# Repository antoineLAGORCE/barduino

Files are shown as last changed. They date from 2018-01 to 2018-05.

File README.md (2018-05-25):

# BARDUINO ARNOUX LAGORCE GUADALIX
CE PROJET EST REALISE DANS LE CADRE DE:
ALLER POLYTECH NICE-SOPHIA

## DESCRIPTION DU PROJET
  Nous allons sortir du traditionnel. Notre projet se base sur le même principe qu'un barduino comme on les a déja vu auparavant
sauf que nous allons le faire avec une esthétique circulaire en plus d'une reconnaissance vocale transmise par technologie
bluetooth.
  En effet nous allons faire bouger les bouteilles, plaçant le verre fixe sur la base. Un moteur pas à pas fera bouger le support plaçant la bouteille désirée sur le verre. Une fois sa tâche accomplie, la tige rentre en jeu pour pousser le doseur à l'aide d'un servo moteur.
  Tout cela est possible gràce aux pièces modélisées à notre choix sur l'ordinateur qui nous permettent de tout relier.
  Nous avons choisi 7 cocktails de base et l'Aléatoire.

## LISTE DU MATRIEL NECESSAIRE
  - [x] Servo moteur;
  - [x] Moteur pas à pas;
  - [x] Puce bluetooth;
  - [x] Tige imprimée en 3D avec son support vertical;
  - [x] Support de fixation du moteur pas à pas modélisé;
  - [x] Helice entrainant le support des bouteilles;
  ### Dont le matériel à commander est
  - [x] Support pour les bouteilles
  Support pour les bouteilles Support por les bouteilles

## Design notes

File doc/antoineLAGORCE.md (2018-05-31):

Séance du 21/12/2017:
Nous allons faire un barduino a reconnaisance vocale.
Nous hesitons a faire un bar circulaire ou murale
cela conciste a demander un cocktail a haute voie et notre barduino réalise notre demande. 
nous avons vu sur https://www.youtube.com/watch?v=K0hTqzQLlWo un exemple de barduino avec des distributeaurs 

Séance de 10/01/2018:
nous sommes donc partie sur un barduino circulaire. 
nous alons faire tourner un verre comme un "petit train" qui va se positionner en dessous des bouteilles avec une petite tige qui va monter et descendre pour appuyer sur les doseurs et verser une dose de liquide.
nous avons commencé a lister le matériels et les techniques que nous allons utiliser pour concevoir notre barduino. 
nous avons encore quelque hesitations sur la technique pour faire tourner le verre sur des rails (comme un petit train)
nous avons réalisé un planning peu détailler de ce que nous allons faire. 

séance du 19/01/2018:
nous avons finalisaé la conception de notre projet. en effet, nous avons décidé de faire tourner les bouteilles et non le verre. 
puis, nous avons commandé le materiel principale dont noud avons besion. 

séance du 19/02/2018:
nous avons fini le programme bluetooth.
on a fait une liste des objets a découpés:
- 6 cercles (diametre de 8cm) qui vont etre fixés sous les dosseurs pour répartir et augmenter la force de la tige qui va ouvrir les valves
- une tige de longueur 13 cm et de diamtre 1 cm
- un demi-cercle de diametre 8cm qui va etre fixé sur la tigue pour répartir la force de la tige 
- des plaques en bois que nous allons découpé pour fixer le cervo moteur, la tige et pour faire un socle pour le verre afin de cacher le systeme pour faire monter la tige

séance du 12/03/2018:
nous avons assambler les programmes des deux moteurs avec celui du bluetooth. c'est a dire que : on envoyer une commande avec l'application sur le téléphone, en fonction de la commande, le moteur à courant continue tourne dans différents sens (dans le but de faire tourner l'axe avec les bouteilles et de s'arreter à l'endroit où l'on veut) puis le servo moteur se met en marche afin de monter
une tige qui verse la bouteille dans le verre, puis à nouveau le moteur à courant continue, le servo moteur ... 

séance 5/04/2018:
nous avons trouvé une application sur le téléphone qui comprend la reconnaissance vocale. nous avons rencontré quelques problème pour pouvoir mettre ce que nous disions sur le telephone dans une variable afin de pouvoir faire les différents coktails.

seance 2/05/2018 :
nous avons réglé les problèmes liés à la reconnaissance vocale. 
j'ai réflechis à l'assemblage des pieces (par exemple viser un support en bois sur la tige qui permet d'actionner les doseurs). j'ai finis de limer les pièces imprimer à l'imprimante 3D pour qu'elles puissents s'assembler. 

seance du 7/05/2018:
j'ai recuperé les rislans pour pouvoir attacher les cercles en bois aux doseurs afin de répartir la force qui va être appliquée. j'ai découpé les orreils du moteur car elles empechées les bouteilles de tourner.

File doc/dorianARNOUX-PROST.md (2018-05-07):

Séance du 21/12/2017 :
On a assemblé le trinome composé de Antoine Lagorce, César Guadalix et moi-meme. On a choisi de faire un barduino avec une spécialité : la reconnaissance vocale. On pense faire un barduino avec verre fixe, et c'est les bouteilles qui tournent au dessus sur un axe circulaire.

Séance du 10/01/2018 :
Après de nombreux schémas, on a trouvé le "design" de notre projet, nous allons utiliser un cylindre en PVC de 140mm de diamètre et faire tourner autour un petit train sur des rails qui va contenir l'arduino + moteur et soutenir la plateforme du verre. Nous voulions commander le matériel cette semaine mais on ne trouvait pas quel système utiliser pour faire tourner la plateforme autour de l'axe central (qui est fixe). On a partagé les taches pour la semaine prochaine de manière a etre plus efficaces.

Séance du 19/01/18 :
Liens pour petits trains :
https://www.ebay.com/itm/LIONEL-FASTRACK-LOT-TRACK-INNER-SIDING-PACK-switch-train-fast-loop-6-12044-NB-/310541188464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
http://www.newhallstation.com/store/product_info.php/products_id/1041
http://www.rueducommerce.fr/produit/touslescadeaux-train-electrique-de-noel-24-pieces-30177768/offre-73395642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

Liens pour doseurs :
https://www.cdiscount.com/vin-champagne/accessoires-vin/distributeur-de-boisson-design-distributeur-alcoo/f-1290911-tec4260435991311.html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|mp

Seance du 19/02/2018 :
J'ai travaillé sur le servo-moteur, trouvé un moteur assez puissant pour lever les valves et regardé quelques codes pour me souvenir de comment ils fonctionnent. J'ai fait fonctionné la puce HC-06 qui ne fonctionnait pas la semaine dernière. 

Séance du 12/03/2018:
J'ai réalisé les différentes fonctions pour chaque cokctail, j'ai du donc assembler les codes pour bluetooth, le servo moteur et le moteur pas a pas  dans un seul programme regroupant tous ces programmes. Pour chaque fonction, il a fallu utiliser des différentes combinaisons entre l'ordre des fonctions prédéfinies pour le servo moteur et le moteur pas à pas.

Séance du 05/04/2018:
J'ai modifié les fonctions des cocktails de maniere a ce que les cables ne s'emmelent pas quand la machine tourne. J'ai aussi testé l'assistant de commande vocale google, pour que le programme réagisse au noms des cockatils.

Seance du 02/05/2018:
J'ai dessiné les parties rondes que l'on va fixer sur les doseurs du bar, nous allons finalement partir sur du bois au lieu du plastique (fragile) de l'imprimante 3D.

Séance du 07/05/2018:
Dans la semaine on est allé récupérer les nouvelles pièces à l'imprimante 3D et découpé les rondins de bois que nous allons fixer sur les doseurs. Je me suis renseigné sur les tiges en pvc qui existent afin d'en avoir sous la main si la tige en plastique de l'imprimante 3D n'est pas assez solide.

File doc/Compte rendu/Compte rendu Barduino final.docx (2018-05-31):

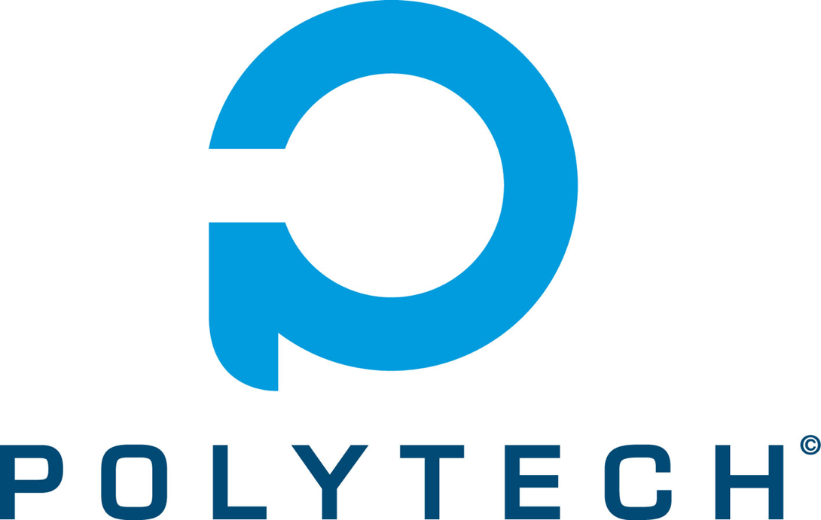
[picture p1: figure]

Compte Rendu Projet Arduino

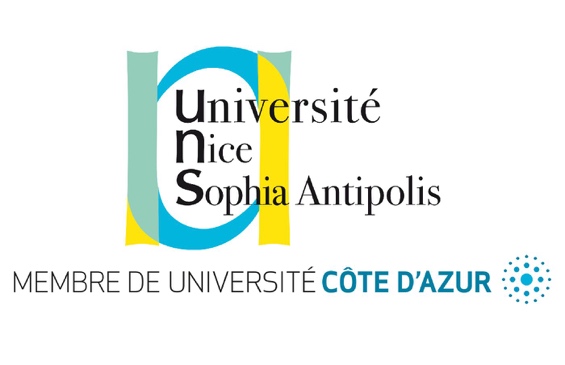
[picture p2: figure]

BARDUINO

Sommaire

I. Introduction
II. De la théorie à la pratique
III. Matériel
IV. Planning
V. Code
VI. Montage
VII. Tests
VIII. Conclusion
I. Introduction

Au cours de cette deuxième année de classe préparatoire nous avons eu l’occasion de pouvoir réaliser notre premier projet officiel en électronique grâce à la technologie Arduino. Dans ce cadre nous avons décidé de mettre en œuvre un bar connecté par technologie Bluetooth à un smartphone courant.

Nos motivations commencent là. De nos jours, 73% des français possèdent un smartphone, ce qui veut dire que ces mêmes 73% ont la possibilité de se faire servir un verre automatiquement commandé avec un téléphone sans avoir besoin de bouger du canapé. Nous sommes partis sur l’originalité d’un Barduino circulaire avec une commande vocale adaptée aux boissons préférées de l’utilisateur. Nous avons pu donc au cours de la réalisation combiner trois domaines qui nous ont permis de tout mettre en relation comme le sont l’informatique, l’électronique et la mécanique.

Nos objectifs principaux ont été de faire un bar qui fonctionne correctement avec une originalité ajoutée : faire le premier Barduino circulaire afin d’ajouter un côté innovatif et design à celui-ci. Nous avons aussi voulu innover du côté pratique en intégrant au Barduino un principe de commande vocale simulant un vrai bar. En effet, le côté « user-friendly » était important pour nous ; nous ne voulions pas que l’utilisateur ait des difficultés à manipuler ce Barduino.

II. De la théorie à la pratique

Avant de commencer à réaliser notre Barduino, il était évident de définir précisément les spécificités de celui-ci. Plusieurs options se sont rapidement mises en place pour réaliser les différentes caractéristiques techniques de notre Barduino.

Notre objectif était de réaliser un Barduino qui fonctionne parfaitement. Pour cela, deux options s’offraient à nous : faire tourner un verre sous les bouteilles ou bien faire tourner les bouteilles avec un verre fixé.

Nous voulions dans un premier temps faire tourner le verre à l’image d’un petit train électrique. Mais, un problème est vite apparu, nous n’avons pas trouvé de rails avec un diamètre suffisamment petit pour faire coïncider le verre avec les bouteilles.

Nous avons donc pris la décision de faire tourner les bouteilles au-dessus d’un verre fixe.

Puis, nous devions trouver un moyen de verser les bouteilles dans le verre. De nouveau, plusieurs options s’offraient à nous. Tout d’abord un système de pompe ou bien un système de doseurs avec un mécanisme qui l’actionnerait. Par souci d’esthétique nous avons décidé d’utiliser les doseurs.

III. Matériels

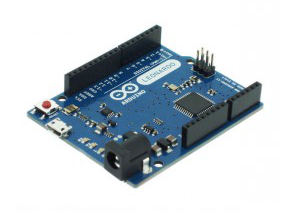
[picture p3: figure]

Tout d’abord nous disposons de notre carte Arduino.

Nous avons commandé la base de notre projet qui comporte déjà 6 doseurs :

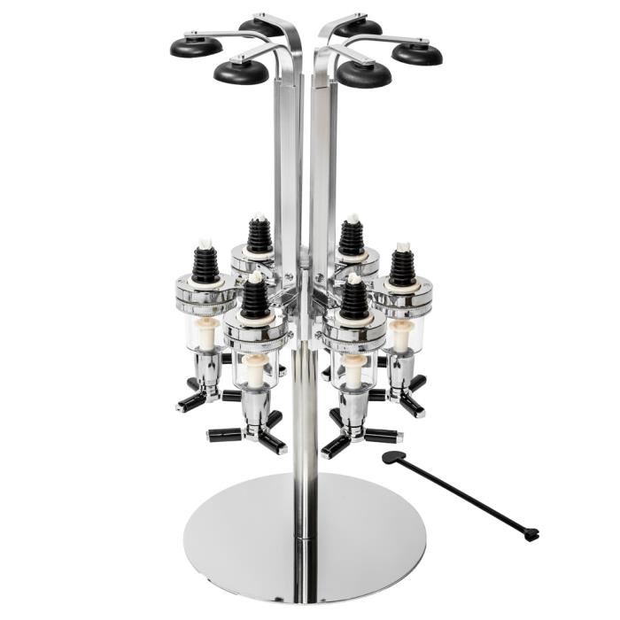
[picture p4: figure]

Les doseurs étant déjà positionnés sur un roulement à billes, il nous fallait un moteur pour pouvoir les faire tourner sur commande.

Nous avons donc décidé d’utiliser un moteur pas à pas car celui-ci est très précis et cela nous permettait de faire tourner les bouteilles et de les arrêter précisément à l’endroit où le verre est positionné. De plus, nous avons imprimé en 3D une pièce qui s’emboite avec le moteur pour que celui-ci puisse avoir de l’incidence sur les bouteilles.

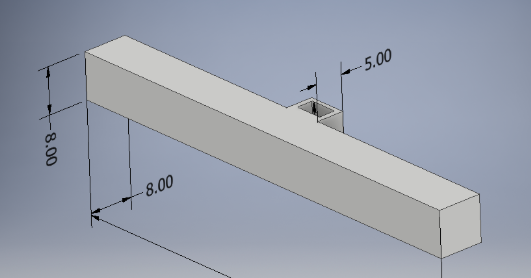
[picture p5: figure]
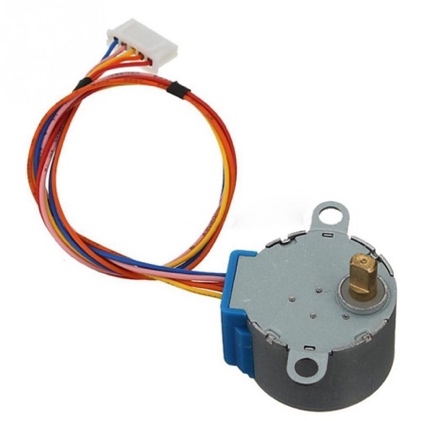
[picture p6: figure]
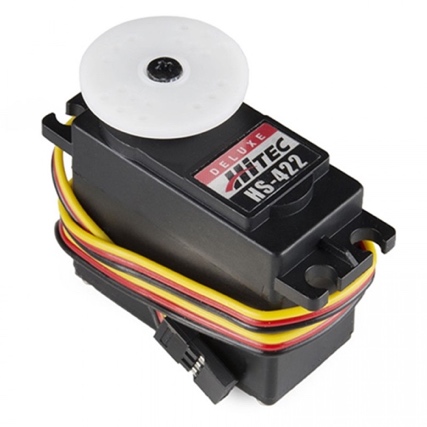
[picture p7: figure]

De plus, le système permettant d’actionner les doseurs comporte deux servo-moteurs avec une tige et une pièce servant à la maintenir pour chaque servo-moteur.

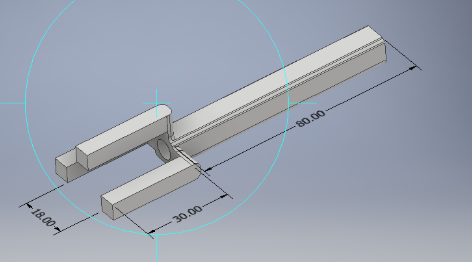
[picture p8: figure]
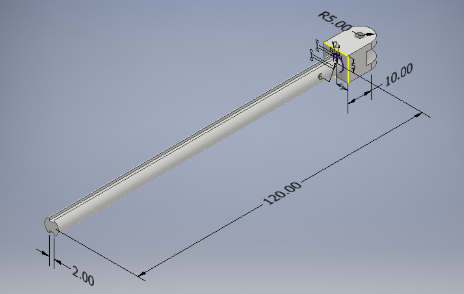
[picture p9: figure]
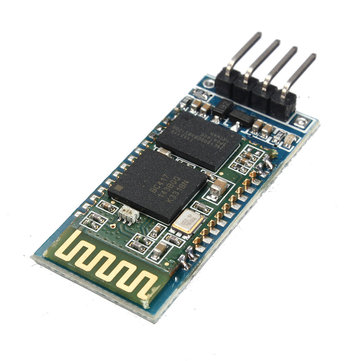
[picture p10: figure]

Enfin, nous disposons d’une puce Bluetooth HC-06 pour effectuer la connexion entre le téléphone et notre projet.

IV. Planning
- Fin Décembre – Fin Janvier :

Réflexion sur le choix du projet et son fonctionnement.

- Début Février:

Choix de faire tourner le support au lieu de faire tourner le verre autour.

- Février :

Codage des fonctions permettant d’activer les moteurs et de créer les différents cocktails.

- Mars :

Conception des pièces à l’imprimante 3D.

- Avril :

Assemblage des moteurs avec la base.

- Fin Avril début Mai :

Tests et faibles modifications de la structure.

V. Code
1. Bluetooth

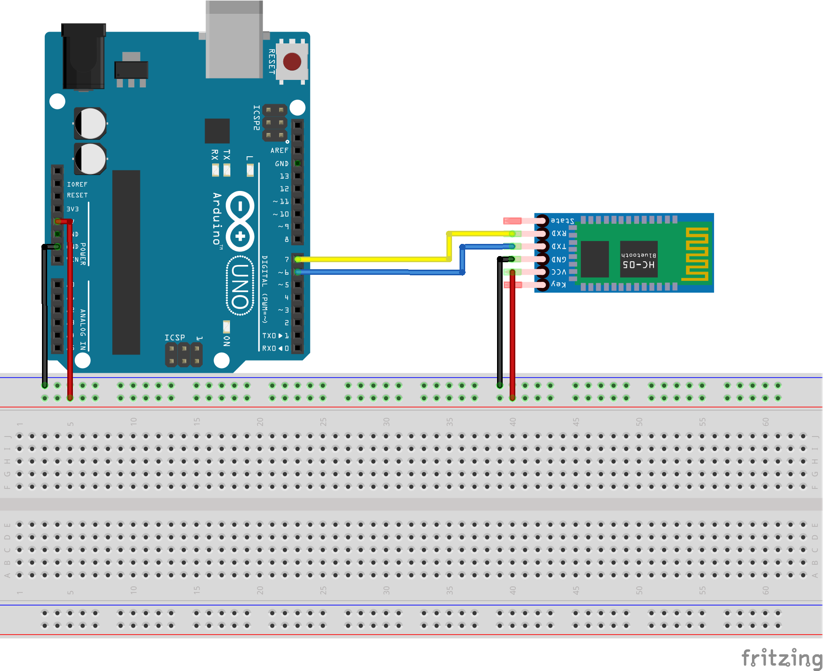
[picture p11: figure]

Nous avons commencé par reprendre ce que nous avions vu en cours afin d’effectuer la connexion Bluetooth entre la puce HC-06 et le téléphone. Nous avons donc effectué les branchements suivants :

Le but de notre projet étant de commander par la voie un cocktail, nous devions trouver un système de reconnaissance vocale. Nous avons donc utilisé une application (Arduino Voice Control) comprenant déjà la reconnaissance vocale et qui renvoie en chaine de caractère ce qui a été dit par l’utilisateur. Ensuite, nous avons codé notre programme afin que chaque cocktail que nous avons défini réalise l’action qu’il doit réaliser. Pour cela, nous avons utilisé une variable pour chaque cocktail avec des instructions différentes pour chacun. Donc si la commande effectuée par l’utilisateur correspond bien à un cocktail, alors les actions à effectuer sont exécutées. Voici un exemple de cocktail :

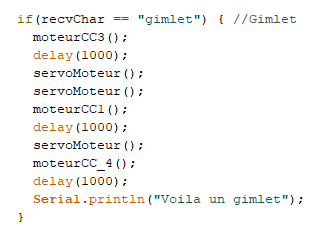
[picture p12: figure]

2. Moteur pas à pas

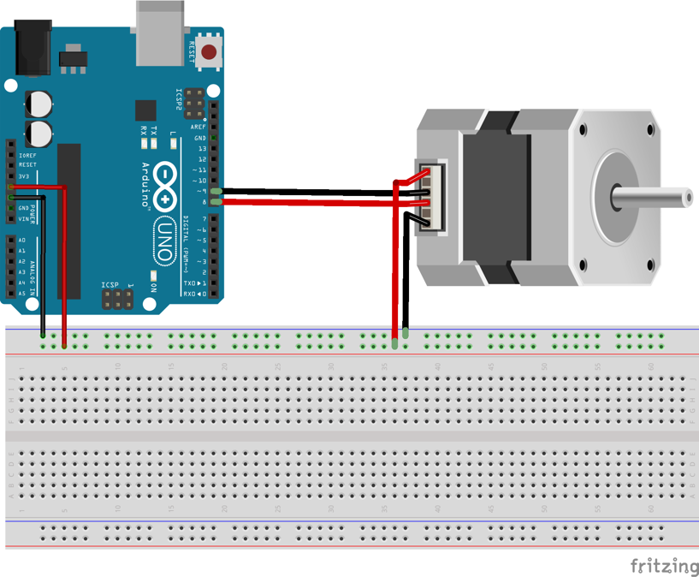
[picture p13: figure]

Nous avons effectué les branchements suivants :

Le but du moteur pas à pas est de faire tourner les bouteilles. Comme nous disposons de 6 bouteilles, ce moteur devait être capable de faire précisément un-sixième de tour. Ici, on définit dans Paso un tableau de séquences de bits qui vont permettre de faire bouger le moteur. La fonction moteurCC1() correspond à un sixième de tour, elle doit donc permettre de déplacer le bar jusqu'à la bouteille de gauche.

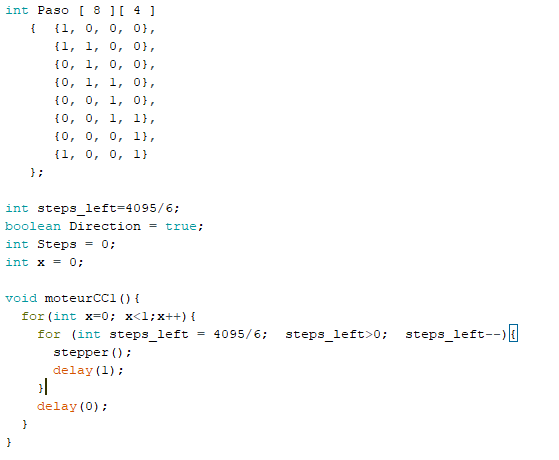
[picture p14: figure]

3. Servo moteur

Nous avons effectué les branchements suivants :

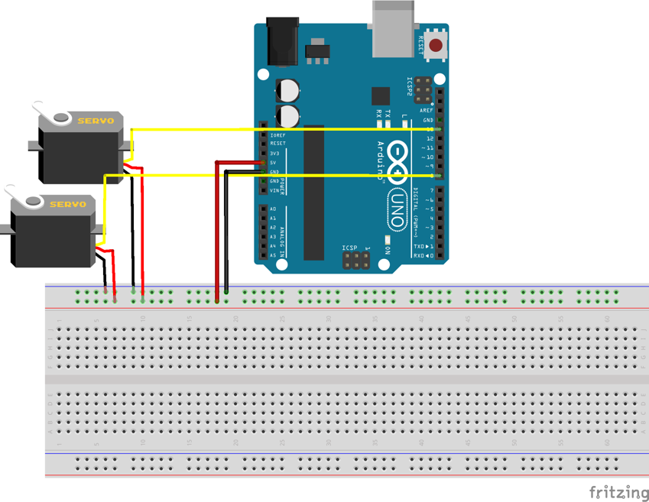
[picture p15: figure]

Le but du servo-moteur est de faire monter une tige, la faire tenir pendant quelques secondes et la redescendre. Nous avons donc réalisé deux boucles : dans la première boucle le servo-moteur se positionne à la position initiale, il effectue une rotation de 55 degrés puis il revient à sa position initiale dans la deuxième boucle. Mais, nous avions besoin qu’il reste à sa position intermédiaire pendant quelques secondes. Pour cela, nous avons ajouté une condition avec un temps d’attente lorsque le servo moteur se trouve à cette position. Voici notre fonction qui actionne le servo moteur :

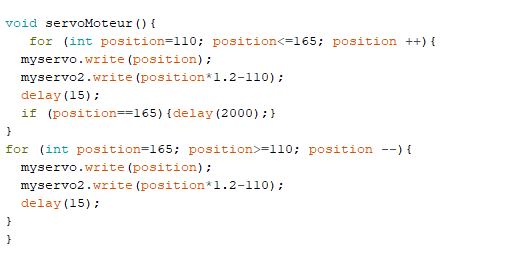
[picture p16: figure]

VI. Montage

Après avoir récupéré les pièces imprimées en 3D, nous avons dus assembler celles-ci. En effet, toutes les pièces que nous avons imprimées sont nécessaires pour que nos moteurs puissent agir sur la base de notre projet.

Tout d’abord nous avons fixé des cercles en bois sur chaque doseur et également vissé un cercle en bois à la tige d’un servo-moteur afin de répartir et donc d’augmenter la force de la tige qui provient du servo moteur dans le but d’actionner les doseurs.

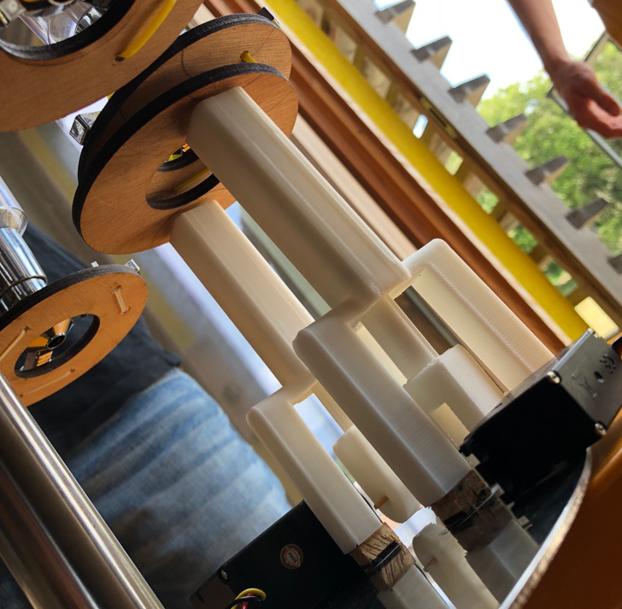
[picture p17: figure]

Ensuite, nous avons assemblé la pièce que nous avons conçu pour qu’elle puisse s’emboiter avec le moteur pas à pas. Le but étant de pouvoir faire tourner les bouteilles.

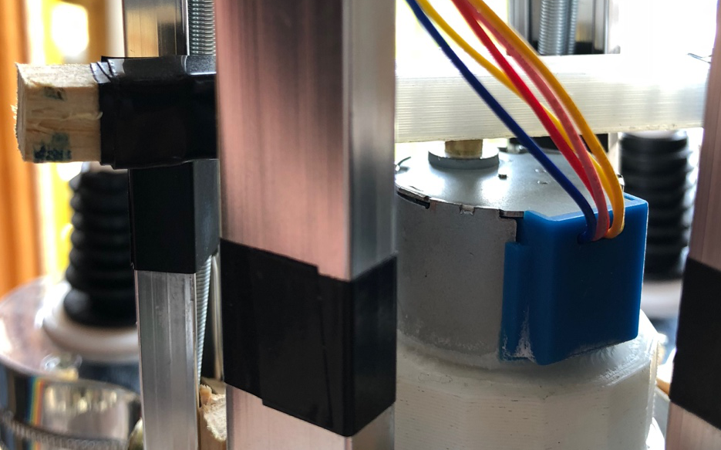
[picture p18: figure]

Enfin, nous avons assemblé les différentes parties de code que nous avions effectuées pour faire fonctionner les moteurs à tour de rôle en fonction du cocktail demandé.

Pour finir, nous avons effectués le branchement de tout le matériel :

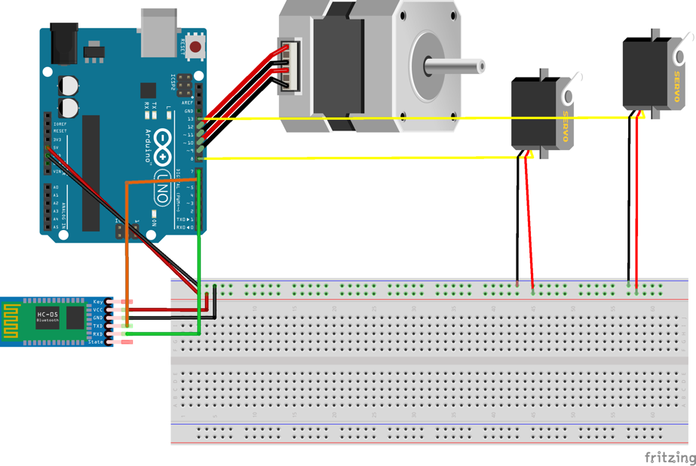
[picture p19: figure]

VII. Tests

I – Connexion arduino-téléphone

Ce premier test était primordial, car nous avions besoin de la connexion bluetooth pour appeler nos fonctions qui activeraient les moteurs. Malgré quelques problèmes pour initialiser la connexion entre le téléphone et le module HC-06, nous avons rapidement réussi à avoir une connexion qui fonctionne.

II – Servo moteur

Durant ce test, nous avons testé la force du servo-moteur, s’il avait assez de puissance pour soulever le doseur, et ce fut un échec. Effectivement, malgré la présence de cercles de bois sur la tige et sur les doseurs, la force n’était toujours pas assez réparti. On a décidé d’aller chercher un nouveau servo-moteur, plus petit, qui allait aider l’autre moteur à bien répartir la force sur le doseur.

III – Moteur pas à pas

Concernant le moteur pas à pas, on s’est rendu compte qu’il ne tournait pas comme indiqué dans les fonctions. En effet, il forçait contre les tiges de la base du bar, même lorsqu’il y avait très peu de poids dessus. On en a conclu au début que c’était dû aux fils qui s’entremêlaient et qui exerçaient une force contraire au mouvement de rotation du moteur. On a donc décidé de tester à nouveau mais cette fois en écartant le diamètre de la base autour du moteur. Le moteur forçant toujours contre les tiges, on a déduit de ces tests qu’il n’est pas assez puissant.

VIII. Conclusion

La satisfaction du groupe n’est pas tout à fait optimale vu les erreurs insignifiantes que nous avons eu au cours du projet, par rapport aux erreurs qu’on pensait avoir. Nous avons eu la sensation d’avoir pu régler les erreurs les plus difficiles à surpasser mais des erreurs théoriquement moins importantes, nous n’avons pas pu les régler.

En revanche, une satisfaction globale du groupe est présente grâce à la combinaison des points forts de chaque élément de l’équipe séparément et à la répartition des tâches. Nous avons abouti à un résultat correct malgré les difficultés eu pendant le développement. Ce projet nous a beaucoup apporté sur le plan expérimental, c’est à dire que nous avons tous aimé travailler ensemble.

Nous pouvons conclure que le Barduino pourrait être encore amélioré pendant nos années en cycle ingénieur avec une perfection de la partie dosage vu le manque de puissance du servo-moteur qui entraîne la tige. Nous pourrons ainsi tester d’autres moteurs plus puissants ou même partir sur la même idée d’utiliser un servo-moteur identique afin de donner une puissance double pour actionner le doseur. Enfin, pour pouvoir donner la possibilité aux utilisateurs d’iPhones d’utiliser notre Barduino, nous pourrions créer une application similaire à Voice Control Arduino mais pour iOS.

Barduino Antoine Lagorce Dorian Arnoux-Prost César Guadalix Merino

Antoine Lagorce 31 Mai 2018 Dorian Arnoux-Prost César Guadalix Merino

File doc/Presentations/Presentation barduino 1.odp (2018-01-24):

## Barduino

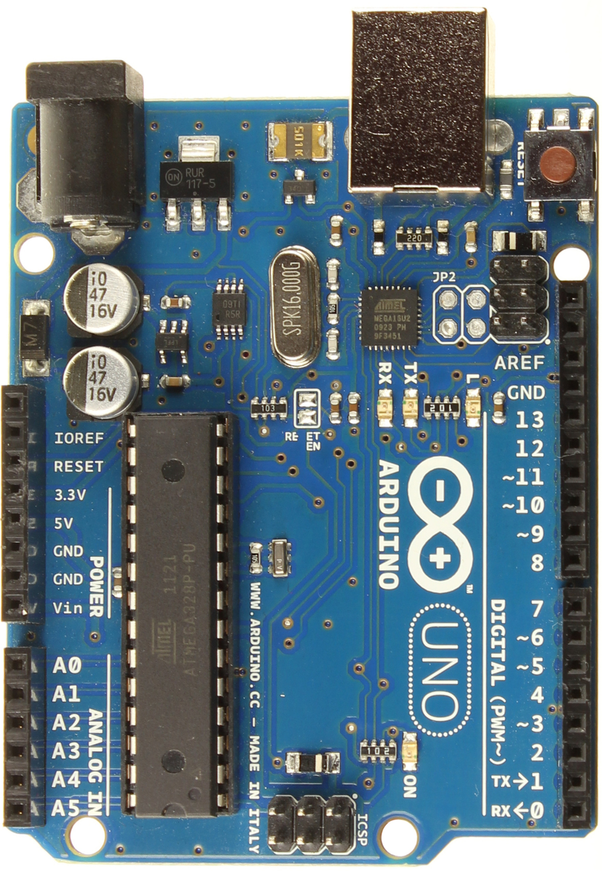
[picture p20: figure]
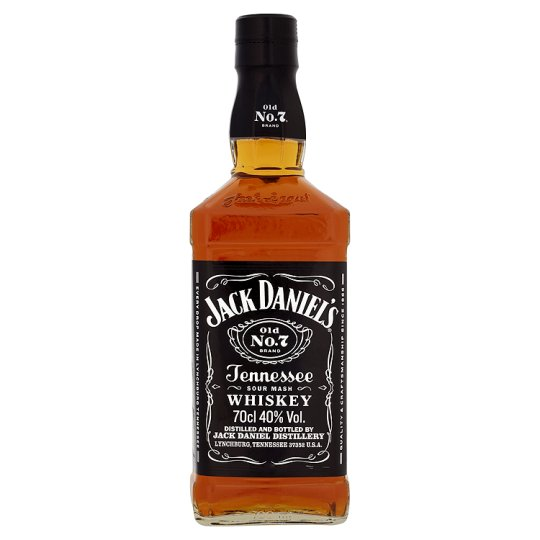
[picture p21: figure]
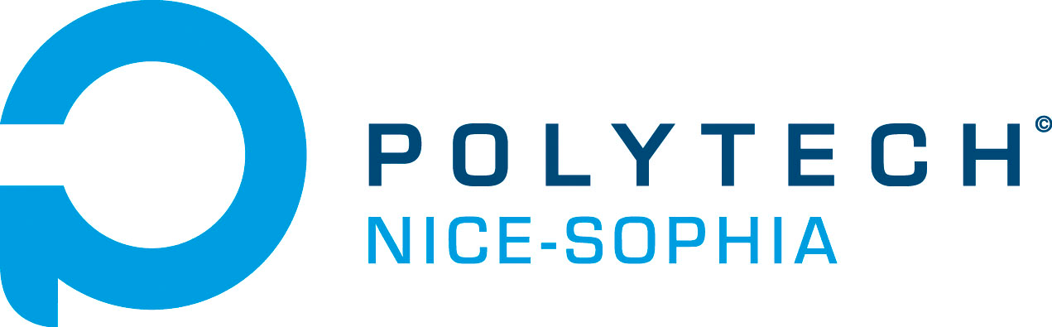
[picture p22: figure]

Antoine Lagorce

César Guadalix

Dorian Arnoux-prost

## Sommaire

- Motivations, objectifs
- Fonctionnement
- Matériel
- Planning
- Conclusion

## Nos motivations

- Recherche
- Sujet qui nous plait à tous les trois
- Réaliser un barduino original
- Fonctionner correctement

Nos objectifs

## Son fonctionnement

- Une base fixe
- Rails autour de la base → faire tourner le verre
- Verser le liquide → tige mobile

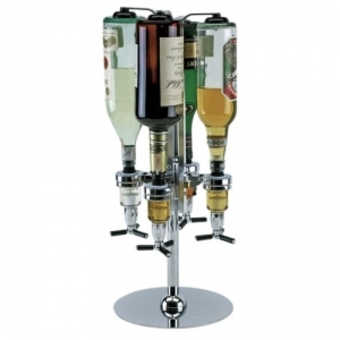
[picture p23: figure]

## Son fonctionnement

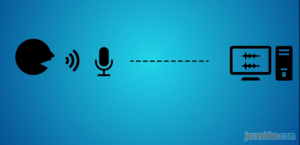
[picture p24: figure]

  Communication bluetooth entre téléphone et arduino
- Ajout d'un système de reconnaissance vocale


## Matériel

- Une base cylindrique
- 6 doseurs de boisson
- Tige découpée au laser
- 1 servo-moteur
- Module Bluetooth

## Planning

- Avant réception matériel :
    - coder la communication arduino/téléphone & app
    - coder programme pour verser la dose
- Après réception matériel :
    - assemblage des différentes parties
    - coder programme pour rails
    - première phase de test

## Conclusion


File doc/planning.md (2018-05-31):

# Planning

### Matériel nécessaire : 2 servo-moteurs, 6 doseurs pour fixer les bouteilles dessus (lien ci-dessous), un puce de reconnaissance vocale, axe metallique central, (roulement a bille).

### Doseurs : https://www.vidaxl.fr/e/8718475885115/distributeur-dalcool-mural-professionnel-pour-6-bouteilles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

## Fin Décembre - Fin Janvier

Réflexion sur le choix du projet et son fonctionnement.

## Début Février

Choix de faire tourner le support au lieu de faire tourner le verre autour.

## Février

Codage des fonctions permettant d'activer les moteurs et de créer les différents cocktails.

## Mars

Conception des Pieces à l'imprimante 3D.

## Avril

Assemblage des moteurs avec la base

## Fin Avril - Début Mai

Tests

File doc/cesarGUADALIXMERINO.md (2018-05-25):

Séance du 21 Décembre 2017:

Nous avons décider de travailler sur un projet déjà travaillé auparavant avec des subtilités particulières du groupe.Nous voulons
en effet faire un barduino avec reconnaissance vocale. Le but deu projet est de pouvoir choisir et commander sa boisson juste
en parlant. Nous avons en tête aussi de faire possible un barduino circulaire mais cela n'est pas encore décidé.

Séance du 10 Janvier 2018:

Nous avons réfléchi a la manière dont le mouvement entre les bouteilles et le verre va se faire. Nous avons décidé de faire
tourner le verre autour des bouteilles disposées en cercle grâceà l'aide de rails disposés d'un système comme celui des train
électrique. L'idéé est de faire passer du courant dans les rails pour faire avancer le train. Celui-ci s'arrêterai à l'aide
d'aimants. Nous avons réfléchi aussi aux pièces à commander pour la prochaine séance.

Séance du 19 Janvier 2018:

Nous avons été à la recherche de du matérier pour faire tourner le verre autour d'un support de bouteilles comme celui
situé sur le README d'accueil. Les aimants utilisés seront pas difficiles à trouver mais nous avons eu des soucis pour trouver
des rails pour un train électrique qui tournera autour du support. Le problème est de trouver ces rails conformes à la taille
du diamètre du support puisque nous avons pas trouvé des rails d'un diamètre si petit. Il faudra cintinuer à chercher.

Séance du 06 Février 2018:

Nous avons finallement mis de côté l'idéé de faire tourner le verre autour du support pour passer à faire tourner le support
lui-même. Une fois le support de bouteilles reçu nous avons constater que c'était possible de fixer un moteur pas à pas qui
fera tourner le support. En conséquence notre verre restera fixe.

Séance du 19 Février 2018:

Nous avons commencé à coder la partie qui concerne le moteur qui va faire tourner le support. Le but est de faire reconnaître
à la carte de quel côté est plus proche la bouteille désirée pour faire tourner le moteur dans le sens correct. 

Séance du 12 Mars 2018:

Nous avons mis en relation le travail fait de la part de tout le monde pendant les vacances. Une fois le code tu servo moteur
qui va soulever la tige pour le doseur écrit, nous l'avons mis à la suite du code du moteur pas à pas qui tournera les bouteilles.
Nous avons rencontré des difficultés au niveau des pas du moteur. Lorsque nous mettons les deux programmes ensemble, nous arrivions
pas à faire tourner les bouteilles le nombre de pas qu'on veut, il faisait moins de pas que ce on voulait. Mais nous avons reussi
à le régler.

Séance du 26 Mars 2018:

Nous avons présenté l'avance du projet ainsi que fait des mesures pour commencer à concevoir les pièces que nous devons imprimer
en 3D. Nous avons téléchargé le logiciel Autodesk qui nous servirá à modéliser notre tige et son tuner qui nous servirons à activer
les doseurs, ainsi que l'hélicoptère, qui assemblé au moteur pas a pas et son support feront tourner la partie suppérieur du support.

Séance du 5 Avril 2018:

Pendant que Dorian et Antoine améliraient les fonctions des coktails pour la comande vovale j'ai modélisé sur le logiciel le support
du moteur pas à pas et la tige doseuse.

Séance du 9 Avril 2018:

Cette séance-ci j'ai fini de modélisé l'ensemble des pièces pour ainsi pouvoir passer au FabLab et passer à l'action. Tout de suite
l'après-midi nous sommes passés au FabLab pour donner les fichiers STL au responsable du laboratoire.

Séance du 2 Mai 2018:

Pendant le temps de la dernière séance et celle-ci nous avons eu un problème avec le résultat des pièces. En effet, je n'avais pas
sur la marge d'erreur de l'imprimante 3D ce qui fait que les pièces qui nécéssitaient une précision extrème comme le support du
pas à pas, j'ai du les remodéliser. Avec succès cette fois, nous avons avons modélisé des cercles en bois que nous allions fixer
à la partie inférieure des doseurs.

Séance du 7 Mai 2018:

Durant de temps nous sommes repassé au FabLab pour récupérer les nouvelles pièces ainsi que pour découper le bois à la découpeuse
laser et opter à des alternatives de tige fabriquée dans un autre matériel plus résistant que le matériel utilisé par l'imprimante.
Nous avos donc pu faire des tests d'enchainements mécaniques entre les pièces.

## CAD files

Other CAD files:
doc/pieces/Ensemble Doseur.iam
doc/pieces/L'Hélico.ipt
doc/pieces/La Couronne.ipt
doc/pieces/Support pasApas.ipt
doc/pieces/Tige.ipt
doc/pieces/Tunel.ipt

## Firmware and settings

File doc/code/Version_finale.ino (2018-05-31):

// RX 7
// TX 6
//Servo 8, 13
// Moteur CC 9,10,11,12




#include <SoftwareSerial.h>  //Software Serial Port  
#define RxD 6    //Pin 6 pour RX, PB2 sur votre board, a brancher sur le TX du HC-06
#define TxD 7    //Pin 7 pour TX, PB3 sur votre board, a brancher sur le RX du HC-06
SoftwareSerial BTSerie(RxD,TxD);  

#include <Servo.h>
Servo myservo;
Servo myservo2;

int Paso [ 8 ][ 4 ] 
   {  {1, 0, 0, 0},
      {1, 1, 0, 0},
      {0, 1, 0, 0},
      {0, 1, 1, 0},
      {0, 0, 1, 0},
      {0, 0, 1, 1},
      {0, 0, 0, 1},
      {1, 0, 0, 1}
   };

#define IN1  12
#define IN2  11
#define IN3  10
#define IN4  9



int steps_left=4095/6;
boolean Direction = true;
int Steps = 0; // Define el paso actual de la secuencia
int x = 0;

void setup(){ 
     pinMode(IN1, OUTPUT);
     pinMode(IN2, OUTPUT);
     pinMode(IN3, OUTPUT);
     pinMode(IN4, OUTPUT);
     Serial.begin(9600);
      myservo.attach(8,0,180);  // attaches the servo on pin 8 to the servo object
      myservo.write(110);
      myservo2.attach(13,0,180);
      myservo2.write(0);
  
  pinMode(RxD, INPUT);  
  pinMode(TxD, OUTPUT); 
  BTSerie.begin(9600); 
    Serial.println("En attente de la commandes AT"); 
    delay(100);
  
  BTSerie.print("AT+VERSION");  //Demande le NÂ° de version 
  delay(1000);  

   }

void loop()
      {

  
 String recvChar;  
  //On lit caractere par caractere sur le BTSerie et on affiche sur le Terminal Serie  
  if (BTSerie.available()) {  //Ces fonctions moteurCC sont valables pour le moteur avec la tige vers le haut
    recvChar = BTSerie.readString();  
    
 

    
    if(recvChar == "vodka cranberry") { //Vodka cranberry
      servoMoteur();
      moteurCC1();
      delay(1000);
      servoMoteur();
      servoMoteur();
      servoMoteur();
      moteurCC_2();
      delay(1000);
      servoMoteur();
      moteurCC1();
      delay(1000);
      Serial.println("Voila un vodka cranberry");
      
      }

      
    if(recvChar == "Bay breeze") { //Bay Breeze
      servoMoteur();
      moteurCC1();
      delay(1000);
      servoMoteur();
      moteurCC1();
      delay(1000);
      servoMoteur();
      moteurCC_2();
      delay(1000);
      Serial.println("Voila un bay breeze");
    }

    if(recvChar == "all in one") { //Hole in one
      servoMoteur();
      moteurCC2();
      delay(1000);
      servoMoteur();
      servoMoteur();
      moteurCC3();
      delay(1000);
      servoMoteur();
      moteurCC_5();
      delay(1000);
      Serial.println("Voila un Hole in one");
    }


    if(recvChar == "hula hoop") { //Hoola Hoop
      moteurCC_1();
      delay(1000);
      servoMoteur();
      moteurCC2();
      delay(1000);
      servoMoteur();
      moteurCC2();
      delay(1000);
      servoMoteur();
      moteurCC_3();
      delay(1000);
      Serial.println("Voila un Hoola Hoop");
    }


    if(recvChar == "gimlet") { //Gimlet
      moteurCC3();
      delay(1000);
      servoMoteur();
      servoMoteur();
      moteurCC1();
      delay(1000);
      servoMoteur();
      moteurCC_4();
      delay(1000);
      Serial.println("Voila un gimlet");
    }





    if(recvChar == "screwdriver") { //Screwdriver
      servoMoteur();
      moteurCC_1();
      delay(1000);
      servoMoteur();
      servoMoteur();
      servoMoteur();
      moteurCC1();
      delay(1000);
     Serial.println("Voila un screwdriver");
    }


    if(recvChar == "supreme") { //Supreme
      servoMoteur();
      moteurCC1();
      delay(1000);
      servoMoteur();
      moteurCC1();
      delay(1000);
      servoMoteur();
      moteurCC1();
      delay(1000);
      servoMoteur();
      moteurCC1();
      delay(1000);
      servoMoteur();
      moteurCC1();
      delay(1000);
      servoMoteur();
      moteurCC_5 ();
      delay(1000);
      Serial.println("Voila un supreme");
    }



    
    Serial.println(recvChar);  //ecriture
  }
  //On lit caractere par caractere sur le terminal et on affiche sur le BT Serie 
  if (Serial.available()) {  
    recvChar = Serial.read(); //lecture
   // BTSerie.write(recvChar);  //ecriture
  }




}

void stepper()            //Avanza un paso
   {  digitalWrite( IN1, Paso[Steps][ 0] );
      digitalWrite( IN2, Paso[Steps][ 1] );
      digitalWrite( IN3, Paso[Steps][ 2] );
      digitalWrite( IN4, Paso[Steps][ 3] );

      SetDirection();
   }

void stepper_()            //Avanza un paso
   {  digitalWrite( IN1, Paso[Steps][ 3] );
      digitalWrite( IN2, Paso[Steps][ 2] );
      digitalWrite( IN3, Paso[Steps][ 1] );
      digitalWrite( IN4, Paso[Steps][ 0] );

      SetDirection();
   }


void SetDirection()
   {  
      if(Direction)
         Steps++;
      else
         Steps--;

      Steps = ( Steps + 8 ) % 8 ;
   }

void servoMoteur(){
   for (int position=110; position<=165; position ++){
  myservo.write(position);
  myservo2.write(position*1.2-110);
  delay(15);
  if (position==165){delay(2000);}
}
for (int position=165; position>=110; position --){
  myservo.write(position);
  myservo2.write(position*1.2-110);
  delay(15);
}
}

void moteurCC1(){
  for(int x=0; x<1;x++){
    for (int steps_left = 4095/6;  steps_left>0;  steps_left--){
      stepper();
      delay(1);
    }

    delay(0);
  }
}


void moteurCC2(){
  for(int x=0; x<2;x++){
    for (int steps_left = 4095/6;  steps_left>0;  steps_left--){
      stepper();
      delay(1);
    }

    delay(0);
  }
}


void moteurCC3(){
  for(int x=0; x<3;x++){
    for (int steps_left = 4095/6;  steps_left>0;  steps_left--){
      stepper();
      delay(1);
    }

    delay(0);
  }
}

void moteurCC4(){
  for(int x=0; x<4;x++){
    for (int steps_left = 4095/6;  steps_left>0;  steps_left--){
      stepper();
      delay(1);
    }

    delay(0);
  }
}


void moteurCC5(){
  for(int x=0; x<5;x++){
    for (int steps_left = 4095/6;  steps_left>0;  steps_left--){
      stepper();
      delay(1);
    }

    delay(0);
  }
}


void moteurCC_2(){
  for(int x=0; x<2;x++){
    for (int steps_left = 4095/6;  steps_left>0;  steps_left--){
      stepper_();
      delay(1);
    }

    delay(0);
  }
}

void moteurCC_1(){
  for(int x=0; x<1;x++){
    for (int steps_left = 4095/6;  steps_left>0;  steps_left--){
      stepper_();
      delay(1);
    }

    delay(0);
  }
}


void moteurCC_3(){
  for(int x=0; x<3;x++){
    for (int steps_left = 4095/6;  steps_left>0;  steps_left--){
      stepper_();
      delay(1);
    }

    delay(0);
  }
}



void moteurCC_4(){
  for(int x=0; x<4;x++){
    for (int steps_left = 4095/6;  steps_left>0;  steps_left--){
      stepper_();
      delay(1);
    }

    delay(0);
  }
}


void moteurCC_5(){
  for(int x=0; x<5;x++){
    for (int steps_left = 4095/6;  steps_left>0;  steps_left--){
      stepper_();
      delay(1);
    }

    delay(0);
  }
}

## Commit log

2018-04-04 Update and rename txt to Description des pièces.md
2018-04-04 Update Description des pièces.md
2018-04-04 Rename Description des pièces.md to Reedme.md
